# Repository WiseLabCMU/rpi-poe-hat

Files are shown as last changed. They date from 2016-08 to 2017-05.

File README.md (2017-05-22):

# RPi Power-over-Ethernet Hat

Give your RPi-0 ethernet and Power-ver-Ethernet (POE).  The hat uses the ENC28J60 chipset from Microchip to provide an 10Base-T 802.3af compatible interface for your RPi over SPI. The board negotiates power from your POE-enabled switch shared between 5V and 3.3V outputs at up to 9 Watts.

## Hardware Overview

PoE Hat top view

PoE Hat top view with RPi

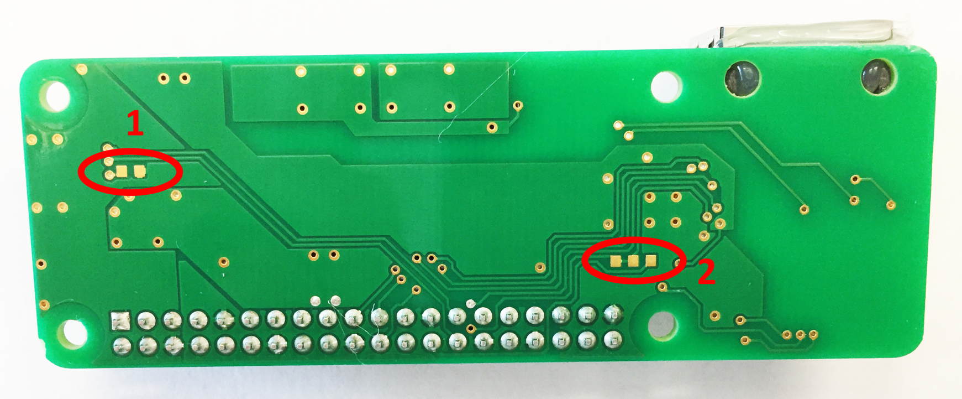
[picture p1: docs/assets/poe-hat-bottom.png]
PoE Hat bottom view


### Jumpers

Placing a 0603 jumper across J1 pulls the EEPROM WP line high, preventing writes.

J2 can be used to choose a chip select on the SPI bus. By default, CS0 is connected by a trace under one of the jumpers. To change it, cut the trace with a hobby knife and place a 0603 jumper across the right-most pads in the previous picture

## Configuring your RPi

For the latest Raspbian image, go to https://www.raspberrypi.org/downloads/raspbian/. 

### Enable SPI

1. run `raspi-config` 
2. select `9 Advanced Options`
3. select `A6 SPI`
4. select `yes` to enbale SPI
5. select `yes` to automaticaly load kernel module
6. select `<Finish>`
7. select `yes` to reboot

### Enable ENC28J60 Overlay

Add the this line to the `/boot/congig.txt`:

`dtoverlay=enc28j60`

After this line is added the Raspberry Pi will automatically load the device on boot.

## Files and Directories

`hardware/RPI0E.sch` - Eagle CAD schematic for the hat.

`hardware/RPI0E.brd` - Eagle CAD board for the hat.

`hardware/bom.xlsx` - Spreadsheet with bill of materials

`hardware/datasheets/` - datasheets for the board components, as well as some part drawings.

For information on EEPROM configuration visit https://github.com/raspberrypi/hats .

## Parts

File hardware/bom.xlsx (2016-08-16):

 |  |  | Unit Price at Quantity
Part | Desc. | Qty Per Board | 1 | 100 | 500 | 1000
Column1 | Column2 | Column3 | Column4 | Column5 | Column6 | Column7 | Column8 | Column9
RC0603FR-0749R9L | 49.9 Ohm Resistor 0603 | 5 | $0.10 | $0.01 | $0.00348 | $0.00257 | Link (http://www.digikey.com/product-detail/en/yageo/RC0603FR-0749R9L/311-49.9HRCT-ND/730211) | 10
GRM188R71C104KA01D | 0.10µF 16V Ceramic Capacitor X7R 0603 | 4 | $0.10 | $0.01 | $0.01 | $0.00468 | Link (http://www.digikey.com/product-search/en?keywords=490-1532-1-ND) | Enough
RC0603JR-073K9L | 3.9k Ohm Resistor 0603 | 3 | $0.10 | $0.0044 | $0.0027 | $0.00198 | Link (http://www.digikey.com/product-detail/en/yageo/RC0603JR-073K9L/311-3.9KGRCT-ND/729710)
C1608C0G1H070D080AA | 7pF 50V Ceramic Capacitor C0G, NP0 0603 | 2 | $0.10 | $0.03 | $0.02 | $0.02 | Link (http://www.digikey.com/product-search/en?keywords=445-5041-1-ND) | 10
RC0603FR-072K32L | 2.32k Ohm Resistor 0603 | 1 | $0.10 | $0.01 | $0.00348 | $0.00257 | Link (https://www.digikey.com/product-detail/en/yageo/RC0603FR-072K32L/311-2.32KHRCT-ND/729968) | 18
742792651 | 600 Ohm Impedance Ferrite Bead 0603 | 1 | $0.20 | $0.17 | $0.17 | $0.16 | Link (https://www.digikey.com/product-detail/en/wurth-electronics-inc/742792651/732-1593-1-ND/1639537) | 3
GRM188R61C106MA73D | 10µF 16V Ceramic Capacitor X5R 0603 | 2 | $0.35 | $0.15 | $0.11 | $0.10 | Link (http://www.digikey.com/product-search/en?keywords=490-7201-1-ND)
MINISMDC110F-2 | POLYSWITCH 1.1A RESET FUSE SMD | 1 | $0.39 | $0.25 | $0.20 | $0.17 | Link (https://www.digikey.com/product-detail/en/littelfuse-inc/MINISMDC110F-2/MINISMDC110FCT-ND/1045861)
SMBJ5V0A | TVS DIODE 5VWM 9.2VC SMB | 1 | $0.39 | $0.21 | $0.16 | $0.12 | Link (http://www.digikey.com/product-detail/en/fairchild-semiconductor/SMBJ5V0A/SMBJ5V0ACT-ND/1626272)
MB6S-TP | IC RECT BRIDGE 0.5A 600V MBS-1 | 2 | $0.40 | $0.22 | $0.15 | $0.11 | Link (https://www.digikey.com/product-detail/en/micro-commercial-co/MB6S-TP/MB6S-TPMSCT-ND/722466) | 8
CAT24C32WI-GT3 | IC EEPROM 32KBIT 400KHZ 8SOIC | 1 | $0.51 | $0.28 | $0.21 | $0.16 | Link (http://www.digikey.com/product-detail/en/on-semiconductor/CAT24C32WI-GT3/CAT24C32WI-GT3CT-ND/1631159)
TLV1117-33CDCYR | Linear Voltage Regulator IC Positive Fixed 1 Output 3.3V 800mA SOT-223-4 | 1 | $0.62 | $0.42 | $0.33 | $0.26 | Link (http://www.digikey.com/product-detail/en/texas-instruments/TLV1117-33CDCYR/296-21112-1-ND/1217055)
FA-238 25.0000MB-K3 | 25MHz ±50ppm Crystal 10pF 50 Ohm | 1 | $0.69 | $0.46 | $0.46 | $0.46 | Link (https://www.digikey.com/product-detail/en/epson/FA-238%2025.0000MB-K3/SER3692CT-ND/2403465)
EEE-FP1C471AP | 470µF 16V Aluminum Capacitors Radial, Can - SMD 80 mOhm @ 100kHz 2000 Hrs @ 105°C | 1 | $0.96 | $0.47 | $0.40 | $0.40 | Link (http://www.digikey.com/product-search/en?keywords=PCE4436CT-ND) | 1
F980G107MSA | 100µF Molded Tantalum Capacitors 4V 0805 | 1 | $1.26 | $0.75 | $0.57 | $0.50 | Link (http://www.digikey.com/product-search/en?keywords=478-8631-1-ND) | 7
RJCSE538001 | CONN MOD JACK 8P8C R/A SHIELDED | 1 | $1.55 | $1.26 | $1.26 | $1.26 | Link (http://www.digikey.com/product-detail/en/amphenol-commercial-products/RJCSE538001/RJCSE538001CT-ND/3659922) | 2
ENC28J60 | SPI Ethernet Controller | 1 | $3.04 | $2.52 | $2.52 | $2.32 | Link (http://www.microchip.com/wwwproducts/en/en022889)
7490100111A | WE-LAN-10/100-BASE-T | 1 | $3.15 | $2.48 | $2.48 | $2.48 | Link (http://www.digikey.com/product-detail/en/wurth-electronics-inc/7490100111A/732-5711-1-ND/4969381)
AG9800 | PoE Module | 1 | $7.29 | $7.29 | $7.29 | $7.29
 |  | Price Per Board | $23.05 | $17.46 | $16.65 | $16.08
 |  | Total Cost | $23.05 | $1745.53 | $8326.35 | $16078.38

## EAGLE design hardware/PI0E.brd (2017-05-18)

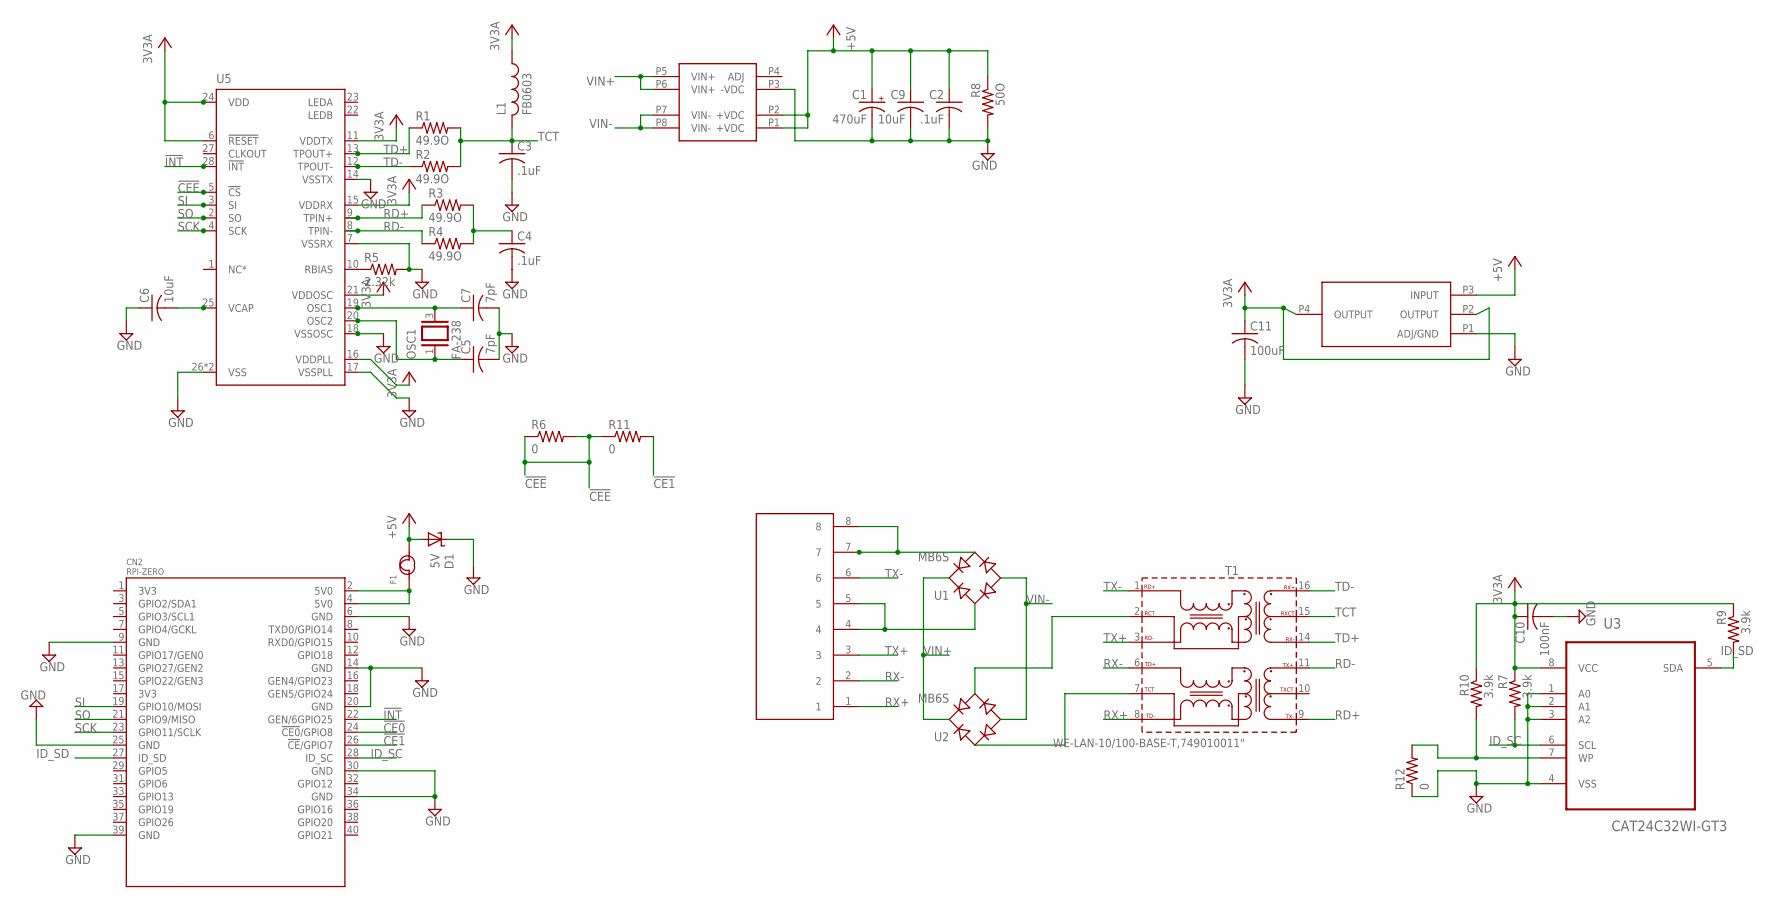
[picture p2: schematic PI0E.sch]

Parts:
C1: 470uF; PANASONIC_F
C2, C3, C4: .1uF; C0603
C5, C7: 7pF; C0603
C6, C9: 10uF; C0603
C10: 100nF; C0603
C11: 100uF; C0805
CN1: RJCSEX38X01XRJCSEX38X01X; RJCSEX38X01X
CN2: RPI-ZERO; RASPBERRYPI_BASTELSTUBE_V13_RASPI_BOARD_B+_FULL
D1: 5V; SMBJ
F1: FUSE'1812'; F1812
L1: FB0603; R0603
OSC1: FA-238
R1, R2, R3, R4: 49.9O; R0603
R5: 2.32k; R0603
R6, R11, R12: 0; R0603
R7, R9, R10: 3.9k; R0603
R8: 50O; R0603
T1: WE-LAN-10/100-BASE-T,749010011"; 749010011
U1, U2: MB6S; SOIC-4
U3: CAT24C32WI-GT3; SOIC127P600X175-8N
U4: TLV1117TLV1117DCY; SOT-223
U5: ENC28J60QFN28-ML_6X6MM; QFN28-ML_6X6MM
U6: AG9800AG9800M; AG9800M

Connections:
5V0@1: CN2.2 (5V0), CN2.4 (5V0), F1.1
!CE0: CN2.24 (!CE0!/GPIO8)
!CE1: CN2.26 (!CE!/GPIO7), R11.2
!CEE: R6.1, R6.2, R11.1, U5.5 (!CS)
!INT: CN2.22 (GEN/6GPIO25), U5.28 (!INT)
+3V3: C10.1, C11.1, L1.1, R7.1, R9.1, R10.1, U3.8 (VCC), U4.P2 (OUTPUT), U4.P4 (OUTPUT), U5.6 (!RESET), U5.11 (VDDTX), U5.15 (VDDRX), U5.16 (VDDPLL), U5.21 (VDDOSC), U5.24 (VDD)
+5V: C1.+, C2.1, C9.1, D1.A, F1.2, R8.1, U4.P3 (INPUT), U6.P1 (+VDC), U6.P2 (+VDC)
GND: C1.-, C2.2, C3.2, C4.2, C5.2, C6.1, C7.2, C9.2, C10.2, C11.2, CN2.6 (GND), CN2.9 (GND), CN2.14 (GND), CN2.20 (GND), CN2.25 (GND), CN2.30 (GND), CN2.34 (GND), CN2.39 (GND), D1.C, R5.2, R8.2, R12.1, U3.1 (A0), U3.2 (A1), U3.3 (A2), U3.4 (VSS), U4.P1 (ADJ/GND), U5.7 (VSSRX), U5.14 (VSSTX), U5.17 (VSSPLL), U5.18 (VSSOSC), U5.26 (VSS), U5.EXP (VSS), U6.P3 (-VDC)
ID_SC: CN2.28 (ID_SC), R7.2, U3.6 (SCL)
ID_SD: CN2.27 (ID_SD), R9.2, U3.5 (SDA)
unnamed: T1.7 (TCT), U2.~1 (AC1)
unnamed: R10.2, R12.2, U3.7 (WP)
unnamed: CN1.7, CN1.8, U1.~2 (AC2)
unnamed: CN1.4, CN1.5, U1.~1 (AC1)
unnamed: T1.2 (RCT), U2.~2 (AC2)
unnamed: C7.1, OSC1.3 (2), U5.19 (OSC1)
unnamed: C5.1, OSC1.1, U5.20 (OSC2)
unnamed: C6.2, U5.25 (VCAP)
unnamed: C4.1, R3.2, R4.2
unnamed: R5.1, U5.10 (RBIAS)
RD+: R3.1, T1.9 (TX-), U5.9 (TPIN+)
RD-: R4.1, T1.11 (TX+), U5.8 (TPIN-)
RX+: CN1.1, T1.8 (TD-)
RX-: CN1.2, T1.6 (TD+)
SCK: CN2.23 (GPIO11/SCLK), U5.4 (SCK)
SI: CN2.19 (GPIO10/MOSI), U5.3 (SI)
SO: CN2.21 (GPIO9/MISO), U5.2 (SO)
TCT: C3.1, L1.2, R1.2, R2.2, T1.15 (RXCT)
TD+: R1.1, T1.14 (RX-), U5.13 (TPOUT+)
TD-: R2.1, T1.16 (RX+), U5.12 (TPOUT-)
TX+: CN1.3, T1.3 (RD-)
TX-: CN1.6, T1.1 (RD+)
VIN+: U1.+, U2.+, U6.P5 (VIN+), U6.P6 (VIN+)
VIN-: U1.-, U2.-, U6.P7 (VIN-), U6.P8 (VIN-)

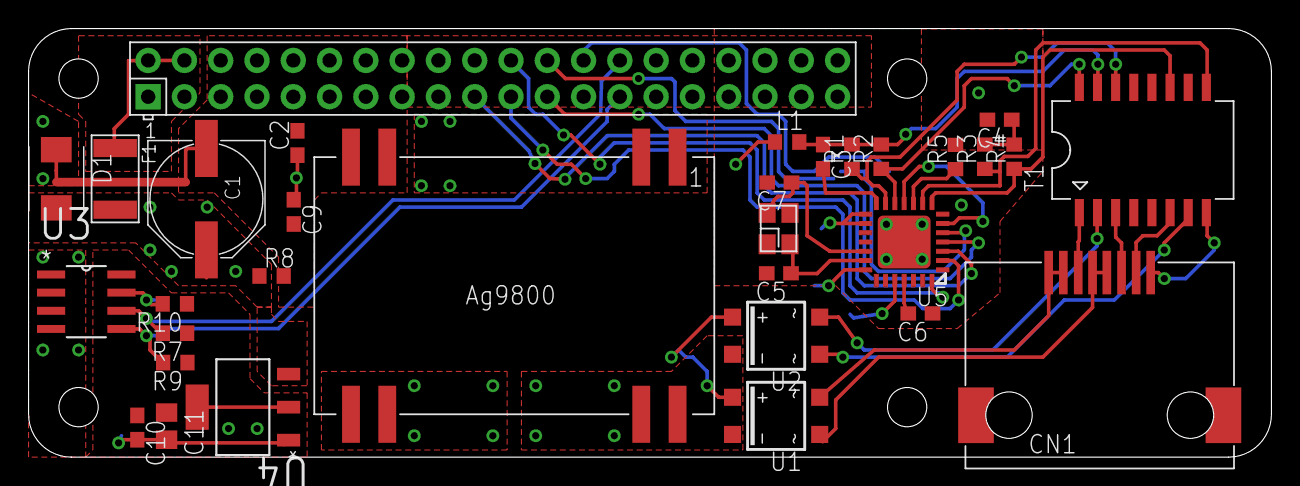
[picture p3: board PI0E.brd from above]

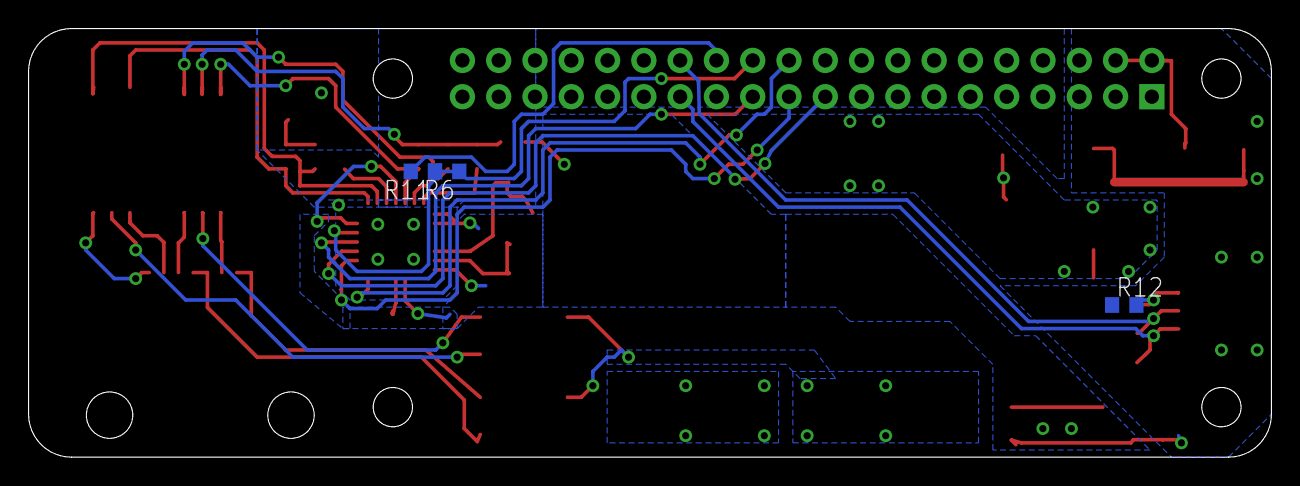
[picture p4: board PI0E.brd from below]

Board: 2 copper layers, 87.0 x 30.0 mm, 35 parts (3 on the bottom side), 33 nets.

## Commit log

2016-04-26 Added datasheets, schematic/board, and bom.
    [PI0E.brd, PI0E.sch, bom.xlsx]
2016-05-08 Cleaning up routing
    [PI0E.brd, PI0E.sch]
2016-05-09 updated drill sizes
    [PI0E.brd]
2016-05-09 Laid ground plane
    [PI0E.brd]
2016-05-09 No more air wires
    [PI0E.brd, PI0E.sch]
2016-05-09 some cleaning of traces
    [PI0E.brd]
2016-05-10 copper pour for the 3.3v regulator. A few cleaned traces.
    [PI0E.brd, PI0E.sch]
2016-05-10 cleared drc issues, cleaned traces
    [PI0E.brd]
2016-05-10 cleaned traces
    [PI0E.brd]
2016-05-11 agr traces
    [PI0E.brd]
2016-05-11 adde files
    [PI0E.brd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]
2016-05-13 fixed missing RX line
    [PI0E.brd, PI0E.sch]
2016-05-18 fixed encj rx/tx power lines. and switch v+ v- pins into the poe module.
    [PI0E.brd, PI0E.sch]
2016-05-18 Updated bom
    [bom.xlsx]
2016-05-18 update to bom. last air wires taken care of on board
    [PI0E.brd, bom.xlsx]
2016-05-18 lengthened qfn pins, fixed drc errors
    [PI0E.brd, PI0E.sch]
2016-05-18 cleaning traces
    [PI0E.brd]
2016-07-01 Initial ENC28J60 fixes: added missing pins and thermal vias, enlarged QFN pads and soldermask exclusions, and rerouted RESET to TP1
2016-07-05 Fixed marking size
    [PI0E.brd]
2016-07-05 Fixed right angle at ocillator
    [PI0E.brd]
2016-07-05 Improved wire appearence
    [PI0E.brd]
2016-07-26 Changed layout to match RPi 0 form factor more closely
    [PI0E.brd, PI0E.sch]
2016-07-26 Fixed silkscreen layer
    [PI0E.brd, PI0E.sch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]
2016-08-16 Changed default CE trace to CE0
    [PI0E.brd, PI0E.sch, bom.xlsx]
2016-08-30 Changed cap from 0603 to 0805
    [PI0E.brd, PI0E.sch]
2017-05-20 moved PCB files to the hardware foldr
    [PI0E.brd, PI0E.sch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]

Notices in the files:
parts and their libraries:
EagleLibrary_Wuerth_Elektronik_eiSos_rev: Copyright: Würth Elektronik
